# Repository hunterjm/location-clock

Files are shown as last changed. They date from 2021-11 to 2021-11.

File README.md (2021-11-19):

# Location Clock

Location Clock is inspired by a love of all things magical, and scientific. A combination of reading Harry Potter with my 8 year old and her "simple machines"
STEM lessons in school, we decided to embark on building our very own physical location clock. Already having Home Assistant setup and configured for my wife
and I, we chose to build upon that along with ESPHome.

## Build Guide

For a detailed build guide please visit the [GitHub Pages Website](https://hunterjm.github.io/location-clock).

## Inspiration

For this project, I drew inspiration from the following similar projects

1. [Magic Clock](https://github.com/brgerig/Magic-Clock): Most of the 3D print files for the assembly were used and/or remixed from here.
2. [Printable Props](https://printableprops.jimdo.com/en/harry-potter/weasley-clock/): Pascal Böcker graciously shared the STLs for the clock hands with me.

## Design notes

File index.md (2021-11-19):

A combination of reading Harry Potter with my 8 year old and her "simple machines"
STEM lessons in school, we decided to embark on building our very own physical location clock. Already having Home Assistant setup and configured for my wife
and I, we chose to build upon that along with ESPHome.

You can follow along here to build your own.

Clock Movement

## Inspiration

For this project, I drew inspiration from the following similar projects

1. [Magic Clock](https://github.com/brgerig/Magic-Clock): Most of the 3D print files for the assembly were used and/or remixed from here.
2. [Printable Props](https://printableprops.jimdo.com/en/harry-potter/weasley-clock/): Pascal Böcker graciously shared the STLs for the clock hands with me.

## Parts

| Part | Quantity | Price | My Source |
|---|---|---|---|
| [nodemcu-32s dev board (38 pin)][1] | 1 | $7-$12 | Amazon |
| [ULN2003 Board w/ Stepper Motor][2] | 4 | $10-$14 | Amazon |
| [Female to Female Jumper Wires][3] | ~26 | $5-7 | Amazon |
| [6V 2A AC/DC Adapter w/ Breakout][4] | 1 | $10-20 | Amazon |
| [Aluminum Telescopic Tubes][5] (1/8, 5/32, 3/16, 7/32) | 1 each size | $7-9 | Amazon |
| Transparent Paper Sheet | 1 | < $1 | On Hand |
| Transparent Vinyl Sticker Sheet | 1 | < $1 | On Hand |
| #10-24 x 3" Machine Screws | 4 | $2-$4 | Big Box Store |
| #10-24 T-Nuts | 4 | $1-$2 | Big Box Store |
| #10-24 Nuts | 24 | $2-$4 | Big Box Store |
| Small Wood Screws | 6 | $1-$2 | Big Box Store |
| 1/2" MDF/Wood Block/Plywood/Scrap Wood | 1 | ? | On Hand |
| White Spray Paint | 1 | ? | On Hand |
| Metallic Silver Spray Paint | 1 | ? | On Hand |
| Super Glue & Wood Glue | 1 | ? | On Hand |
| Old Clock Body (Mine was a Regulator 1114c) | 1 | $25-$35 | Facebook |
| **Total** | | **< $100**  | |

## 3D Printed Parts

| Part | Quantity |
|---|---|
| ULN2003 dual case ([base][6], [cover][7]) | 2 |
| [Mounting Bracket Base][8] | 1 |
| Mounting Bracket Top ([clean][9] or [threaded][10] & [plug][11]) | 1 |
| [Spur Gear 5mm][12] | 4 |
| [Spur Gear 1/8][13] | 1 |
| [Spur Gear 5/32][14] | 1 |
| [Spur Gear 3/16][15] | 1 |
| [Spur Gear 7/32][16] | 1 |
| Clock Hands (not mine to share) | 4 |

## Tools & Supplies

- Phillips Screwdriver
- Exacto Knife
- Super Glue
- Wood Glue
- Wood Clamps
- Spray Paint (White & Metallic Silver)
- Hand saw w/ metal cutting blade
- Wood saw
- Drill & bits
- Pick (helps remove staples)
- Soldering Iron
- (optional) Bench Grinder

## Software

The SVGs in the [graphics folder](https://github.com/hunterjm/location-clock/tree/main/graphics) were created in Inkscape and are editable to change your locations and names. The `names.svg` file has a hidden layer with a to-scale copy of the clock hands I printed for alignment.

## Flash Your ESP32

Insert ESP Web Tools here. Until then, the configuration [can be found here](https://github.com/hunterjm/location-clock/blob/main/esphome/location-clock.yaml).

## The Build

Assembly of the control mechanism was the most difficult part of this project, and I did not take near enough pictures or notes of the process. That being said, a lot of it
is pretty self explanitory, so I will give a general overview of the steps I took and some gotchas along the way.

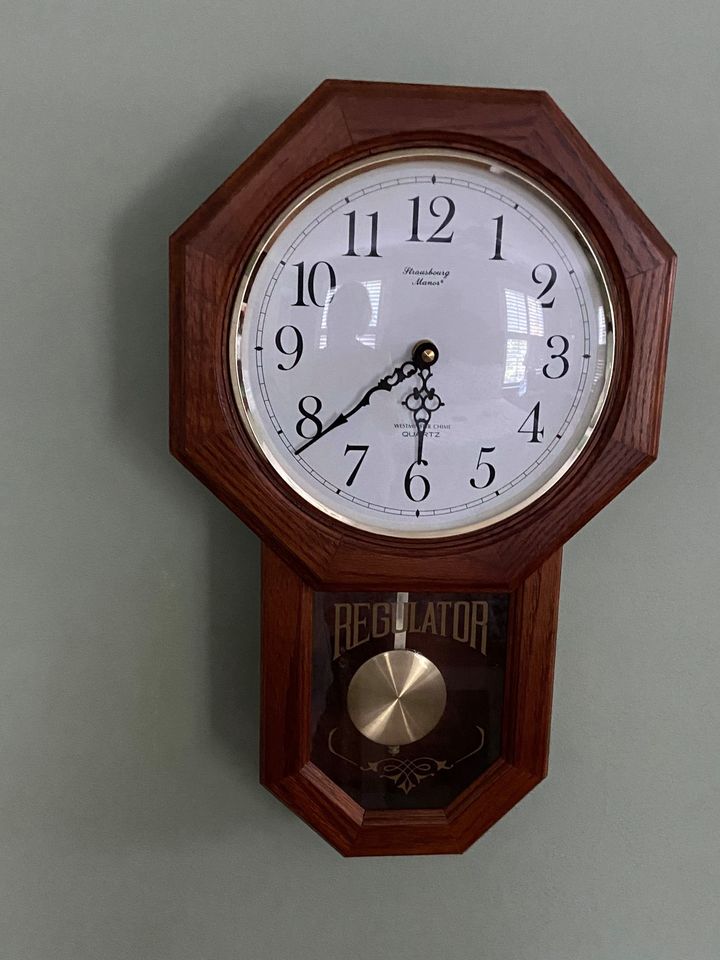
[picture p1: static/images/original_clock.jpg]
Original Clock


### Clock Tear Down

1. 4 screws held the glass assembly of the clock face on from the inside of the body.
2. The clock hands pull right off - they require some pressure.
3. Remove the nut from the clock face, and the old time mechanism should come right out.
4. The glass was held in with a plastic support held by two small screws. Remove the glass so it doesn't break. I also used a razor blade to scrape off the "REGULATOR" text from the glass.
5. The face was held on with 4 L brackets on the side of the clock. I removed it for easier access to build the mechanism.
5. The clock face was attached with some double sided tape and pulled right off.
6. There was a pre-existing 1/2 block of wood in the clock body that was too small and needed to be removed. It was held on with 2 staples, but no glue. I used a pick to pull the staples out.

### Clock Face

1. I spray painted over the aluminum clock face with flat white paint to cover the old numbers.
2. I created a [new face](https://github.com/hunterjm/location-clock/blob/main/graphics/clock_face.svg) in Inkscape and printed it on the vinyl sticker paper.
3. After the paint dried, I was able to apply the new face to the old aluminum one and trim it down with an exacto knife.
Clock Face

### Clock Hands

I am unable to provide the STL files for the hands at this time. I am working with the original author to see if he will let me share them with you all. Either way, the below steps were taken for the clock hands.

1. Spray paint them Metallic Silver.
2. Super Glue them to the transparent paper.
3. Cut out the hands with an exacto knife.
Clock Hands

### Motor Mechanism

Here is where I didn't take nearly enough pictures, and for that I'm sorry!

1. Cut your 1/2" MDF/Scrap Wood/Plywood down to size to fit inside the clock.
2. Using the top mounting bracket as a template, drill holes through the wood for the center piece and the 4 #10 screws in the corners.
3. Hammer in the T-Nuts to the back of the board.
4. Cut off the heads of the 3" #10 screws and thread a nut through to fix the threads. You can use a bench grinder to clean up the cuts, but it's not necessary.
5. Thread the cut off end through the board and into the T-Nuts.
6. Place the top mounting bracket onto the new threaded rods and add 4 nuts.
7. In a clockwise motion, place the motors (attached to the brackets and with the gears on) with the height of two nuts between them. The first two should be facing up, and the following two facing down for the most compact assembly. The gears on the two facing down will actually be lower than those on the motors facing up below them. See picture below for how I have mine setup.
8. Starting with the largest aluminum rod, thread it through the assembly and mark where it contacts the gear and give yourself plenty of space sticking out of the front to attach hands. Cut it with your hand saw, and clean it up with the exacto knife and/or bench grinder. **Make sure you do not bend the rod!** Verify the step smaller rod can still move freely inside.
9. Super glue the gear to one end of the aluminum rod and finess it into the mechanism so the gears are touching.
10. Rinse and repeat for the next 2 rods.  **Read the next line before cutting the last rod!** It's OK if things feel tight and like they aren't lining up properly. Clearances are tight. Until your rods have preassure on all 4 sides from all 4 motors, you will probably have to push and prod and pull and curse.
11. The last rod has a place to fit into the mounting bracket base, so it will be a little longer, and the gear won't be glued on to the end. Make sure you attach the bracket base and measure from the front of the clock!
Motors
12. Wood glue the completed mechanism to the back of the clock face and clamp to let dry.

### Assembly

1. Before re-attaching the clock face, find locations inside the clock body for all of your motor controllers and ESP32. I did not print a mount for my ESP, it's just hanging out back there.
2. Wire up everything inside (except the motors, which are on the clock face). The wiring diagrams are below. The only soldering you will need is to make the power harness. The ESP32 board and each of the ULN2003 boards need 5V power.
3. Re-insert the glass
4. Attach the clock face, watch out for wires, and triple check nothing got unseated during handling.
5. Plug in the motors. Which board you plug each motor into matters if you want to use the out of the box firmware for your ESP32! Check the diagram!
6. Wire management
7. Attach the hands to the face of the clock and align them all to the same location, probably "Home".
8. Power it on and try moving each motor in the Home Assistant Developer Tools "Services" section.
9. Troubleshoot and try again :)

## Wiring Diagrams

### Breadboard
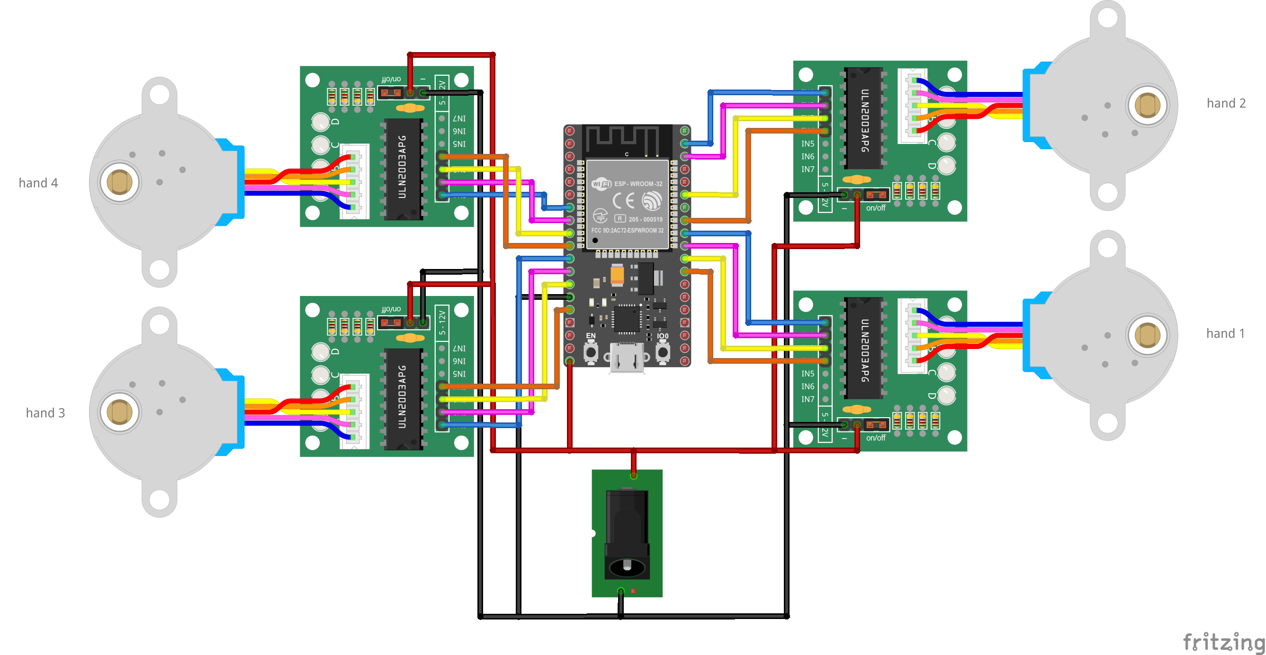
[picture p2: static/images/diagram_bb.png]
Breadboard Diagram


### Schematic
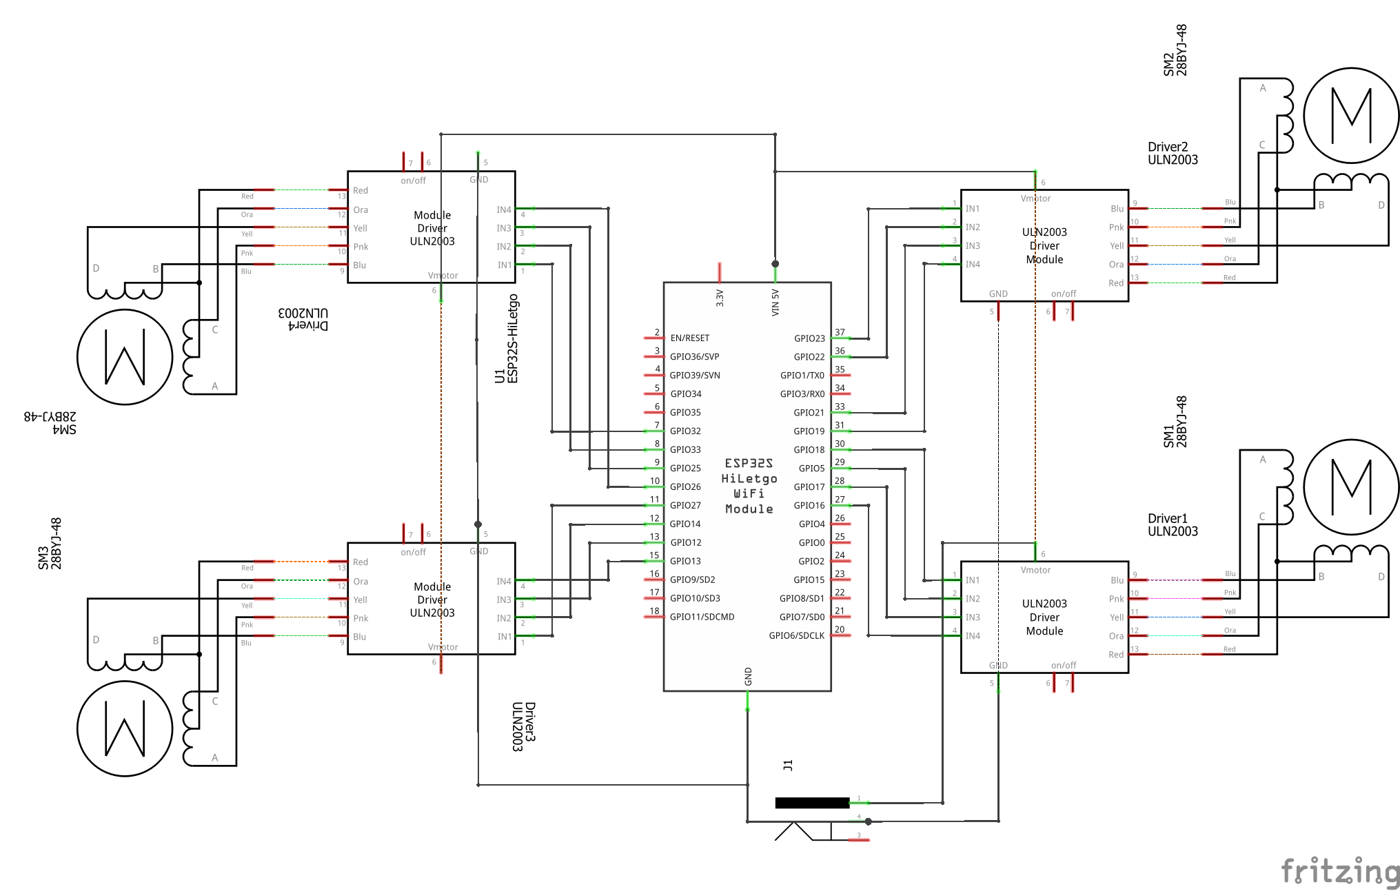
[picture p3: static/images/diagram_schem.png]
Schematic Diagram


## Home Assistant

### Zones

Home Assistant [Zones](https://www.home-assistant.io/integrations/zone/) are the star of the show here. Set up as many Zones as you can for the locations on your clock face.  Don't worry now if the Zone shares the same name as the location on the clock. Not everyone in the household will work at the same place or go to the same school for instance. Name them what they are, we will account for that in the template sensor we create later.

### Template Sensors

To map Zones to locations on the clock and implement some additional logic for locations like "Traveling", "Lost", and "Vacation" we will be using a [Template Sensor](https://www.home-assistant.io/integrations/template/) in Home Assistant. You can see what mine looks like below:

{% raw %}
```yaml
sensor:
  - platform: template
    sensors:
      jason_presence:
        value_template: >
          {% if is_state('person.jason', 'home') %}
            Home
          {% elif is_state('person.jason', 'not_home') or is_state('person.jason', 'Library') %}
            {% if distance('device_tracker.jasons_iphone') > 80 %}
              Vacation
            {% elif as_timestamp(now()) - as_timestamp(states.person.jason.last_changed) > 86400 %}
              Lost
            {% elif is_state('sensor.jasons_iphone_activity', 'Automotive') %}
              Traveling
            {% else %}
              Away
            {% endif %}
          {% elif is_state('person.jason', 'Nana') or is_state('person.jason', 'Gran') %}
            Parents
          {% elif is_state('person.jason', 'Son School') or is_state('person.jason', 'Daughter School') %}
            School
          {% elif is_state('person.jason', 'Dentist') %}
            Doctor
          {% elif is_state('person.jason', 'Charlotte FC') %}
            Event
          {% else %}
            {{ states('person.jason') }}
          {% endif %}
```
{% endraw %}

To better understand the logic here, I have a Zone for "Library". That is where my Wife works, but I do not. I want the "Away" logic to run when I am there. For my "Away" logic, there are 4 possible "Away" states:
1. Vacation: Away, but > 80 km from home.
2. Lost: Away for more than 24 hours excluding "Vacation".
3. Traveling: Away but iPhone reports activity as "Automotive", excluding "Vacation" and "Lost".
4. Away: Simply not home when none of the above special states are met.

### Children

The children aren't old enough for phones yet, and cheap GPS devices targeted for Kids are [notoriously insecure](https://www.troyhunt.com/how-to-track-your-kids-and-other-peoples-kids-with-the-tictoctrack-watch/). Because of this, I am simply using an [Input Select](https://www.home-assistant.io/integrations/input_select/) with all of the clock face locations for the kids hands currently. You can then create automations to automatically change them under certian conditions. For example, if my wife or I enter the Zone for a child's school in the morning, we can place them at "School". Same thing with picking them up in the afternoon. When they get old enough, this can all be automated through the Mobile App like it is for the adults.

### Blueprint

The [blueprint](https://github.com/hunterjm/location-clock/blob/main/homeassistant/blueprints/location-clock.yaml) is meant to create an automation to control each hand. There is a detailed description in the blueprint on how it should be configured. Click the link below to import it!



[1]: <https://www.amazon.com/dp/B0718T232Z>
[2]: <https://www.amazon.com/dp/B015RQ97W8>
[3]: <https://www.amazon.com/dp/B01L5ULRUA>
[4]: <https://www.amazon.com/dp/B08VWG1S1V>
[5]: <https://www.amazon.com/dp/B07VS4823F>
[6]: <https://github.com/hunterjm/location-clock/blob/main/stl_files/ULN2003-dual.stl>
[7]: <https://github.com/hunterjm/location-clock/blob/main/stl_files/ULN2003-dual-cover.stl>
[8]: <https://github.com/hunterjm/location-clock/blob/main/stl_files/mounting-bracket-base.stl>
[9]: <https://github.com/hunterjm/location-clock/blob/main/stl_files/mounting-bracket-top.stl>
[10]: <https://github.com/hunterjm/location-clock/blob/main/stl_files/mounting-bracket-top-threaded.stl>
[11]: <https://github.com/hunterjm/location-clock/blob/main/stl_files/mounting-bracket-top-threaded-plug.stl>
[12]: <https://github.com/hunterjm/location-clock/blob/main/stl_files/spur_gear_5mm.stl>
[13]: <https://github.com/hunterjm/location-clock/blob/main/stl_files/spur-gear-1-8th.stl>
[14]: <https://github.com/hunterjm/location-clock/blob/main/stl_files/spur-gear-5-32nd.stl>
[15]: <https://github.com/hunterjm/location-clock/blob/main/stl_files/spur-gear-3-16th.stl>
[16]: <https://github.com/hunterjm/location-clock/blob/main/stl_files/spur-gear-7-32.stl>

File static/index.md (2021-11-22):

From a combination of reading Harry Potter with my 8 year old and her "simple machines"
STEM lessons in school, we decided to embark on building our very own physical location clock. Already having Home Assistant set up and configured for my wife
and I, we chose to build upon that along with ESPHome.

You can follow along here to build your own.

- [Inspiration](#inspiration)
- [Setup](#setup)
- [Flash Your ESP32](#flash-your-esp32)
- [The Build](#the-build)
- [Wiring Diagrams](#wiring-diagrams)
- [Home Assistant](#home-assistant)

Clock Movement

## Inspiration

For this project, I drew inspiration from the following similar projects

1. [Magic Clock](https://github.com/brgerig/Magic-Clock): Most of the 3D print files for the assembly were used and/or remixed from here.
2. [Printable Props](https://printableprops.jimdo.com/en/harry-potter/weasley-clock/): Pascal Böcker graciously shared the STLs for the clock hands with me.

## Setup

### Parts

| Part | Quantity | Price | My Source |
|---|---|---|---|
| [nodemcu-32s dev board (38 pin)][1] | 1 | $7-$12 | Amazon |
| [ULN2003 Board w/ Stepper Motor][2] | 4 | $10-$14 | Amazon |
| [Female to Female Jumper Wires][3] | ~26 | $5-7 | Amazon |
| [6V 2A AC/DC Adapter w/ Breakout][4] | 1 | $10-20 | Amazon |
| [Aluminum Telescopic Tubes][5] (1/8, 5/32, 3/16, 7/32) | 1 each size | $7-9 | Amazon |
| Transparent Paper Sheet | 1 | < $1 | On Hand |
| Transparent Vinyl Sticker Sheet | 1 | < $1 | On Hand |
| #10-24 x 3" Machine Screws | 4 | $2-$4 | Big Box Store |
| #10-24 T-Nuts | 4 | $1-$2 | Big Box Store |
| #10-24 Nuts | 24 | $2-$4 | Big Box Store |
| Small Wood Screws | 6 | $1-$2 | Big Box Store |
| 1/2" MDF/Wood Block/Plywood/Scrap Wood | 1 | ? | On Hand |
| White Spray Paint | 1 | ? | On Hand |
| Metallic Silver Spray Paint | 1 | ? | On Hand |
| Super Glue & Wood Glue | 1 | ? | On Hand |
| Old Clock Body (Mine was a Regulator 1114c) | 1 | $25-$35 | Facebook |
| **Total** | | **< $100**  | |

### 3D Printed Parts

| Part | Quantity |
|---|---|
| ULN2003 dual case ([base][6], [cover][7]) | 2 |
| [Mounting Bracket Base][8] | 1 |
| Mounting Bracket Top ([clean][9] or [threaded][10] & [plug][11]) | 1 |
| [Spur Gear 5mm][12] | 4 |
| Spur Gear ([1/8][13], [5/32][14], [3/16][15], [7/32][16]) | 1 each |
| Clock Hand ([1][17], [2][18], [3][19], [4][20]) | 1 each |

### Tools & Supplies

- Phillips Screwdriver
- Exacto Knife
- Super Glue
- Wood Glue
- Wood Clamps
- Spray Paint (White & Metallic Silver)
- Hand saw w/ metal cutting blade
- Wood saw
- Drill & bits
- Pick (helps remove staples)
- Soldering Iron
- (optional) Bench Grinder

### Software

The SVGs in the [graphics folder](https://github.com/hunterjm/location-clock/tree/main/graphics) were created in Inkscape and are editable to change your locations and names. The `names.svg` file has a hidden layer with a to-scale copy of the clock hands I printed for alignment. They use the Lumos font face.

## Flash Your ESP32

The ESPHome configuration [can be found here](https://github.com/hunterjm/location-clock/blob/main/esphome/location-clock.yaml). With ESP Web Tools, you can flash and configure your ESP32 directly from a supported browser with the compiled firmware by plugging it in and clicking the button below.

<esp-web-install-button manifest="./firmware/manifest.json"></esp-web-install-button>

<script type="module" src="https://unpkg.com/esp-web-tools@5.2.0/dist/web/install-button.js?module"></script>

## The Build

Assembly of the control mechanism was the most difficult part of this project, and I did not take near enough pictures or notes of the process. That being said, a lot of it
is pretty self explanitory, so I will give a general overview of the steps I took and some gotchas along the way.

Original Clock

### Clock Tear Down

1. 4 screws held the glass assembly of the clock face on from the inside of the body.
2. The clock hands pull right off - they require some pressure.
3. Remove the nut from the clock face, and the old time mechanism should come right out.
4. The glass was held in with a plastic support held by two small screws. Remove the glass so it doesn't break. I also used a razor blade to scrape off the "REGULATOR" text from the glass.
5. The face was held on with 4 L brackets on the side of the clock. I removed it for easier access to build the mechanism.
5. The clock face was attached with some double sided tape and pulled right off.
6. There was a pre-existing 1/2 block of wood in the clock body that was too small and needed to be removed. It was held on with 2 staples, but no glue. I used a pick to pull the staples out.

### Clock Face

1. I spray painted over the aluminum clock face with flat white paint to cover the old numbers.
2. I created a [new face](https://github.com/hunterjm/location-clock/blob/main/graphics/clock_face.svg) in Inkscape and printed it on the vinyl sticker paper.
3. After the paint dried, I was able to apply the new face to the old aluminum one and trim it down with an exacto knife.
Clock Face

### Clock Hands

The [clock hands](#3d-printed-parts) are reproductions of Arthur, Molly, Ron, and Bill's hands from the film made by Pascal Böcker of [Printable Props](https://printableprops.jimdo.com/en/harry-potter/weasley-clock/). I scaled down his originals to fit in my clock face and resized the holes for the aluminum rods I am using.

1. Spray paint them Metallic Silver.
2. Super Glue them to the transparent paper.
3. Cut out the hands with an exacto knife.
Clock Hands

### Motor Mechanism

Here is where I didn't take nearly enough pictures, and for that I'm sorry!

1. Cut your 1/2" MDF/Scrap Wood/Plywood down to size to fit inside the clock.
2. Using the top mounting bracket as a template, drill holes through the wood for the center piece and the 4 #10 screws in the corners.
3. Hammer in the T-Nuts to the back of the board.
4. Cut off the heads of the 3" #10 screws and thread a nut through to fix the threads. You can use a bench grinder to clean up the cuts, but it's not necessary.
5. Thread the cut off end through the board and into the T-Nuts.
6. Place the top mounting bracket onto the new threaded rods and add 4 nuts.
7. In a clockwise motion, place the motors (attached to the brackets and with the gears on) with the height of two nuts between them. The first two should be facing up, and the following two facing down for the most compact assembly. The gears on the two facing down will actually be lower than those on the motors facing up below them. See picture below for how I have mine setup.
8. Starting with the largest aluminum rod, thread it through the assembly and mark where it contacts the gear and give yourself plenty of space sticking out of the front to attach hands. Cut it with your hand saw, and clean it up with the exacto knife and/or bench grinder. **Make sure you do not bend the rod!** Verify the step smaller rod can still move freely inside.
9. Super glue the gear to one end of the aluminum rod and finess it into the mechanism so the gears are touching.
10. Rinse and repeat for the next 2 rods.  **Read the next line before cutting the last rod!** It's OK if things feel tight and like they aren't lining up properly. Clearances are tight. Until your rods have preassure on all 4 sides from all 4 motors, you will probably have to push and prod and pull and curse.
11. The last rod has a place to fit into the mounting bracket base, so it will be a little longer, and the gear won't be glued on to the end. Make sure you attach the bracket base and measure from the front of the clock!
Motors
12. Wood glue the completed mechanism to the back of the clock face and clamp to let dry.

### Assembly

1. Before re-attaching the clock face, find locations inside the clock body for all of your motor controllers and ESP32. I did not print a mount for my ESP, it's just hanging out back there.
2. Wire up everything inside (except the motors, which are on the clock face). The wiring diagrams are below. The only soldering you will need is to make the power harness. The ESP32 board and each of the ULN2003 boards need 5V power.
3. Re-insert the glass
4. Attach the clock face, watch out for wires, and triple check nothing got unseated during handling.
5. Plug in the motors. Which board you plug each motor into matters if you want to use the out of the box firmware for your ESP32! Check the diagram!
6. Wire management
7. Attach the hands to the face of the clock and align them all to the same location, probably "Home".
8. Power it on and try moving each motor in the Home Assistant Developer Tools "Services" section.
9. Troubleshoot and try again :)

## Wiring Diagrams

### Breadboard
Breadboard Diagram

### Schematic
Schematic Diagram

## Home Assistant

### Zones

Home Assistant [Zones](https://www.home-assistant.io/integrations/zone/) are the star of the show here. Set up as many Zones as you can for the locations on your clock face.  Don't worry now if the Zone shares the same name as the location on the clock. Not everyone in the household will work at the same place or go to the same school for instance. Name them what they are, we will account for that in the template sensor we create later.

### Template Sensors

To map Zones to locations on the clock and implement some additional logic for locations like "Traveling", "Lost", and "Vacation" we will be using a [Template Sensor](https://www.home-assistant.io/integrations/template/) in Home Assistant. You can see what mine looks like below:

{% raw %}
```yaml
sensor:
  - platform: template
    sensors:
      jason_presence:
        value_template: >
          {% if is_state('person.jason', 'home') %}
            Home
          {% elif is_state('person.jason', 'not_home') or is_state('person.jason', 'Library') %}
            {% if distance('device_tracker.jasons_iphone') > 80 %}
              Vacation
            {% elif as_timestamp(now()) - as_timestamp(states.person.jason.last_changed) > 86400 %}
              Lost
            {% elif is_state('sensor.jasons_iphone_activity', 'Automotive') %}
              Traveling
            {% else %}
              Away
            {% endif %}
          {% elif is_state('person.jason', 'Nana') or is_state('person.jason', 'Gran') %}
            Parents
          {% elif is_state('person.jason', 'Son School') or is_state('person.jason', 'Daughter School') %}
            School
          {% elif is_state('person.jason', 'Dentist') %}
            Doctor
          {% elif is_state('person.jason', 'Charlotte FC') %}
            Event
          {% else %}
            {{ states('person.jason') }}
          {% endif %}
```
{% endraw %}

To better understand the logic here, I have a Zone for "Library". That is where my Wife works, but I do not. I want the "Away" logic to run when I am there. For my "Away" logic, there are 4 possible "Away" states:
1. Vacation: Away, but > 80 km from home.
2. Lost: Away for more than 24 hours excluding "Vacation".
3. Traveling: Away but iPhone reports activity as "Automotive", excluding "Vacation" and "Lost".
4. Away: Simply not home when none of the above special states are met.

### Children

The children aren't old enough for phones yet, and cheap GPS devices targeted for Kids are [notoriously insecure](https://www.troyhunt.com/how-to-track-your-kids-and-other-peoples-kids-with-the-tictoctrack-watch/). Because of this, I am simply using an [Input Select](https://www.home-assistant.io/integrations/input_select/) with all of the clock face locations for the kids hands currently. You can then create automations to automatically change them under certian conditions. For example, if my wife or I enter the Zone for a child's school in the morning, we can place them at "School". Same thing with picking them up in the afternoon. When they get old enough, this can all be automated through the Mobile App like it is for the adults.

### Blueprint

The [blueprint](https://github.com/hunterjm/location-clock/blob/main/homeassistant/blueprints/location-clock.yaml) is meant to create an automation to control each hand. There is a detailed description in the blueprint on how it should be configured. Click the link below to import it!



[1]: <https://www.amazon.com/dp/B0718T232Z>
[2]: <https://www.amazon.com/dp/B015RQ97W8>
[3]: <https://www.amazon.com/dp/B01L5ULRUA>
[4]: <https://www.amazon.com/dp/B08VWG1S1V>
[5]: <https://www.amazon.com/dp/B07VS4823F>
[6]: <https://github.com/hunterjm/location-clock/blob/main/stl_files/ULN2003-dual.stl>
[7]: <https://github.com/hunterjm/location-clock/blob/main/stl_files/ULN2003-dual-cover.stl>
[8]: <https://github.com/hunterjm/location-clock/blob/main/stl_files/mounting-bracket-base.stl>
[9]: <https://github.com/hunterjm/location-clock/blob/main/stl_files/mounting-bracket-top.stl>
[10]: <https://github.com/hunterjm/location-clock/blob/main/stl_files/mounting-bracket-top-threaded.stl>
[11]: <https://github.com/hunterjm/location-clock/blob/main/stl_files/mounting-bracket-top-threaded-plug.stl>
[12]: <https://github.com/hunterjm/location-clock/blob/main/stl_files/spur_gear_5mm.stl>
[13]: <https://github.com/hunterjm/location-clock/blob/main/stl_files/spur-gear-1-8th.stl>
[14]: <https://github.com/hunterjm/location-clock/blob/main/stl_files/spur-gear-5-32nd.stl>
[15]: <https://github.com/hunterjm/location-clock/blob/main/stl_files/spur-gear-3-16th.stl>
[16]: <https://github.com/hunterjm/location-clock/blob/main/stl_files/spur-gear-7-32.stl>
[17]: <https://github.com/hunterjm/location-clock/blob/main/stl_files/hand-1-1-8th.stl>
[18]: <https://github.com/hunterjm/location-clock/blob/main/stl_files/hand-2-5-32nd.stl>
[19]: <https://github.com/hunterjm/location-clock/blob/main/stl_files/hand-3-3-16th.stl>
[20]: <https://github.com/hunterjm/location-clock/blob/main/stl_files/hand-4-7-32nd.stl>

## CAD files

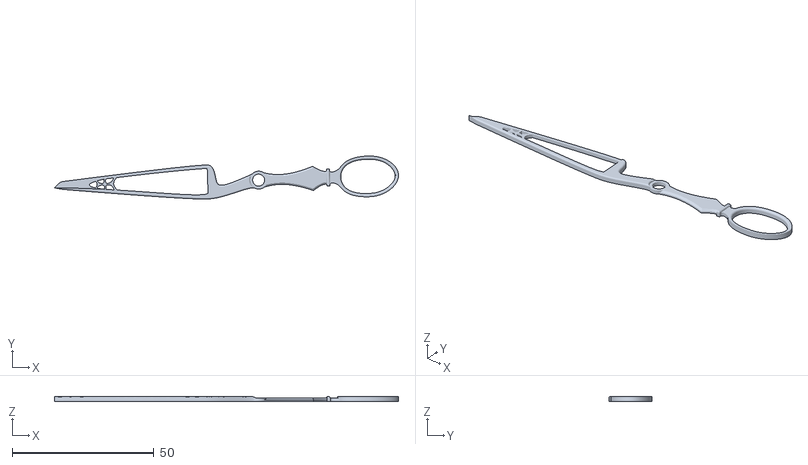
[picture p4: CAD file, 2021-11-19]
stl_files/hand-2-5-32nd.stl
121.4 x 15.2 x 1.80

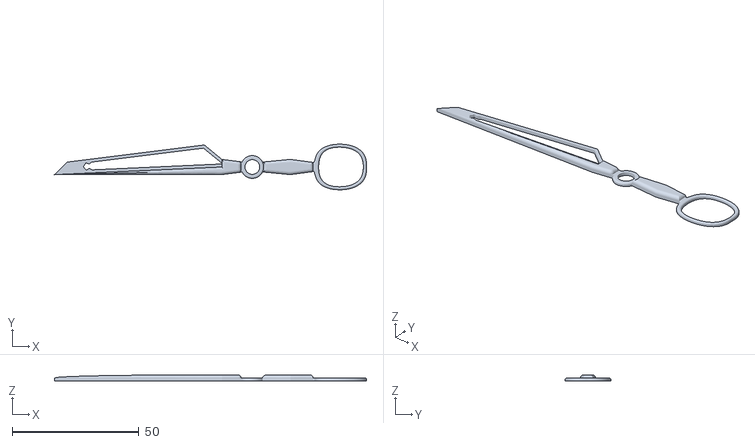
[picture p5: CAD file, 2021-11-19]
stl_files/hand-4-7-32nd.stl
123.0 x 18.0 x 2.40

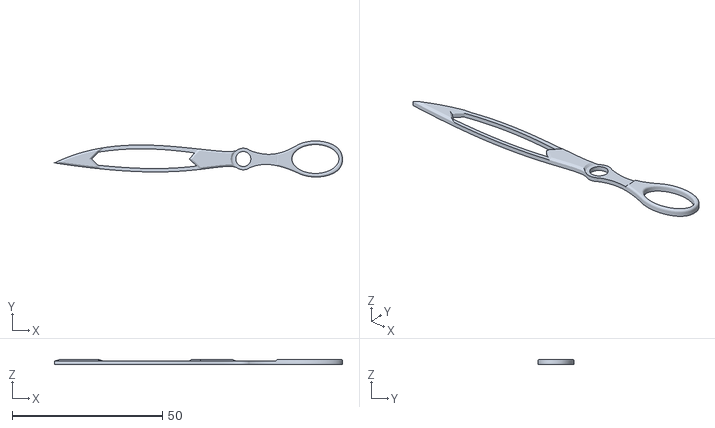
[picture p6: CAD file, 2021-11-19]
stl_files/hand-3-3-16th.stl
95.8 x 12.0 x 1.80

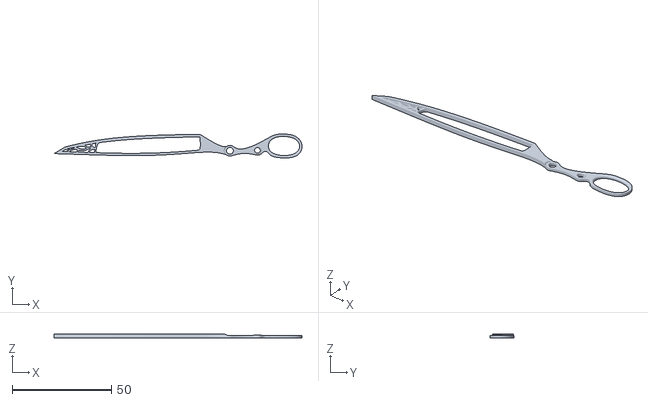
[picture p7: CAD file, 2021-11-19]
stl_files/hand-1-1-8th.stl
124.8 x 12.0 x 1.80

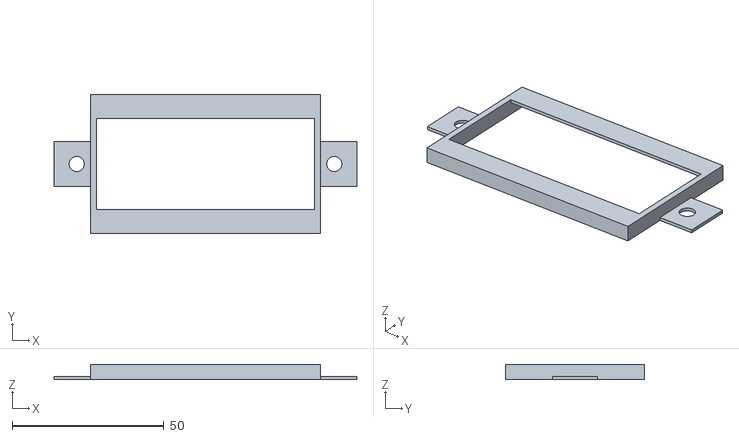
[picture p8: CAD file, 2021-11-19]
stl_files/ULN2003-dual-cover.stl
100.0 x 46.0 x 5.00

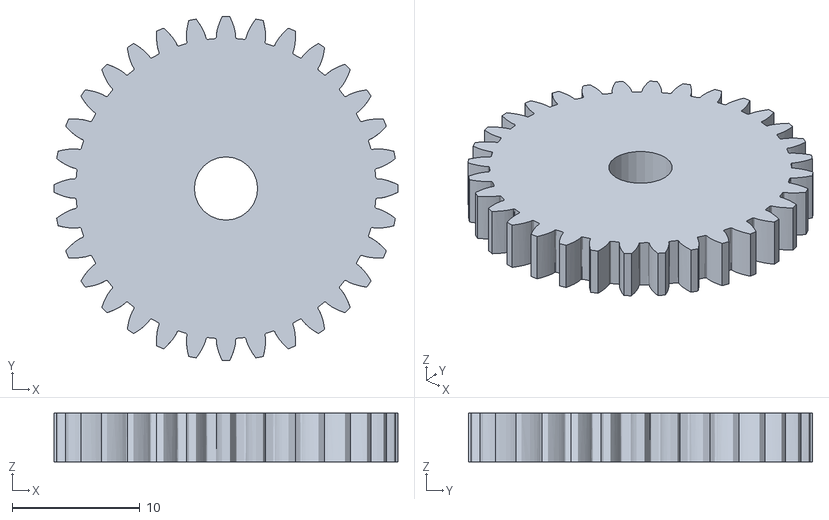
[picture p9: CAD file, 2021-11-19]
stl_files/spur-gear-3-16th.stl
27.0 x 27.0 x 3.81

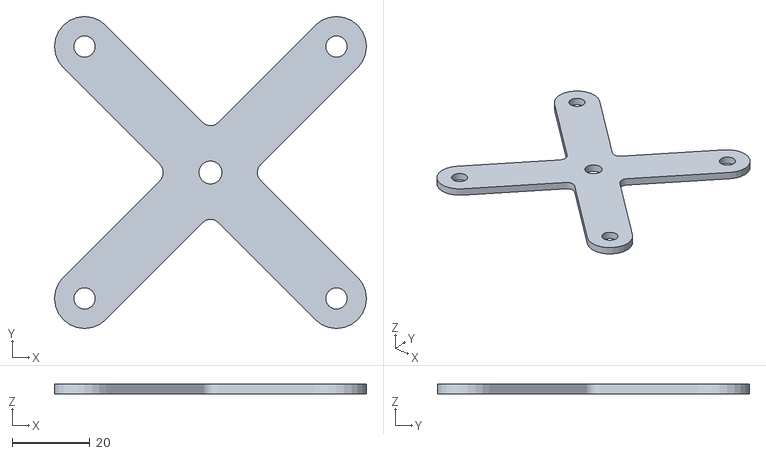
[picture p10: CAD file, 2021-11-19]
stl_files/mounting-bracket-top.stl
80.5 x 80.5 x 2.50

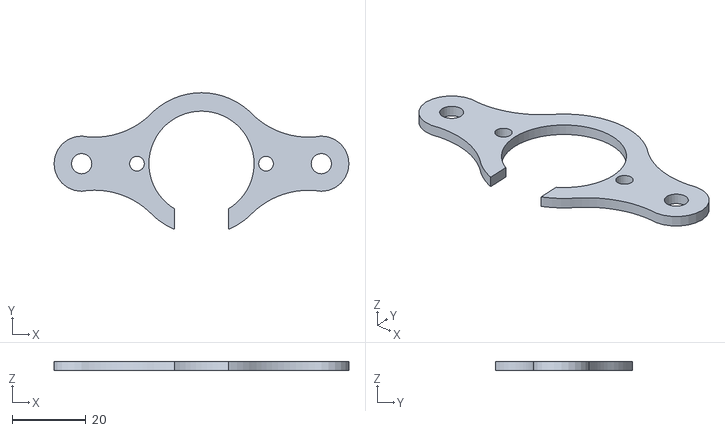
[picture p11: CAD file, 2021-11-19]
stl_files/mounting-bracket.stl
80.0 x 37.0 x 2.50

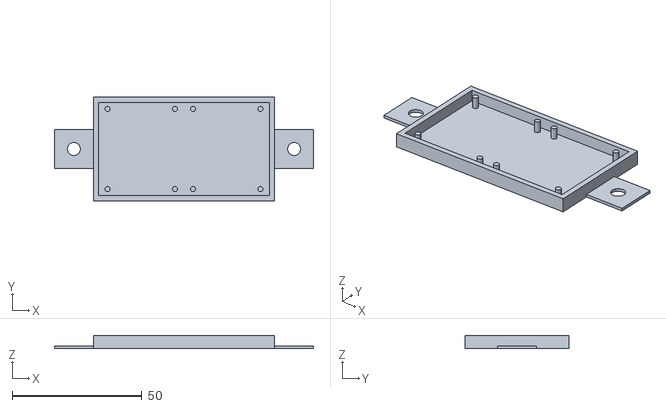
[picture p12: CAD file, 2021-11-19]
stl_files/ULN2003-dual.stl
100.0 x 40.0 x 5.00

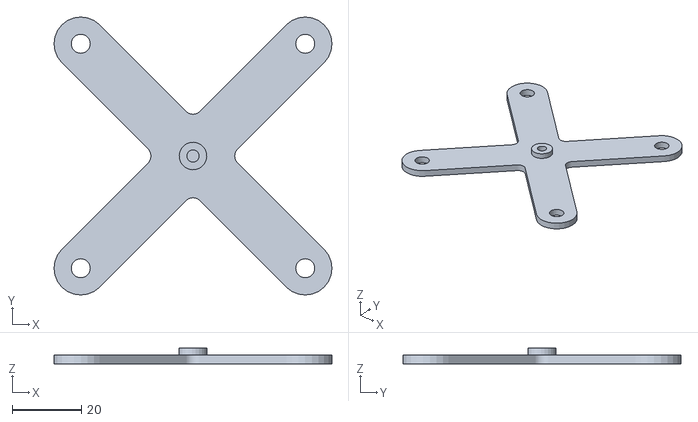
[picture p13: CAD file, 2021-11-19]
stl_files/mounting-bracket-base.stl
80.5 x 80.5 x 4.50

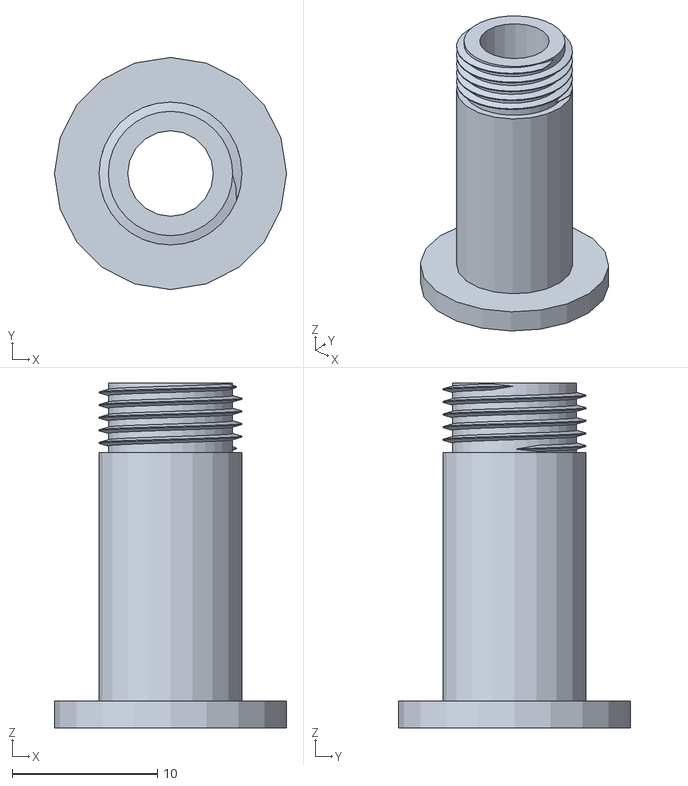
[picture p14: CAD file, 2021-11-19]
stl_files/mounting-bracket-top-threaded-plug.stl
16.0 x 16.0 x 23.8

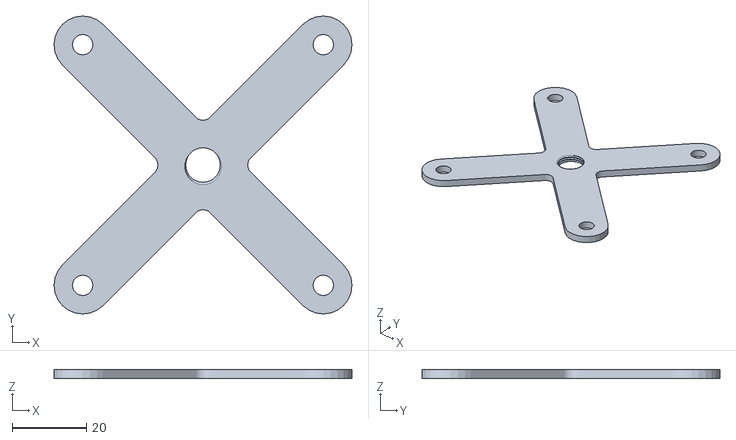
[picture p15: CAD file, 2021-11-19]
stl_files/mounting-bracket-top-threaded.stl
80.5 x 80.5 x 2.50

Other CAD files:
stl_files/spur_gear_5mm.stl
stl_files/spur-gear-5-32nd.stl
stl_files/spur-gear-7-32.stl
stl_files/spur-gear-1-8th.stl

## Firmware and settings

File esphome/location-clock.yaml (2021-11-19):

substitutions:
  name: location-clock

esphome:
  name: "${name}"
  platform: ESP32
  board: nodemcu-32s
  name_add_mac_suffix: true
  project:
    name: hunterjm.location_clock
    version: "1.0.0"

dashboard_import:
  package_import_url: github://hunterjm/location-clock/esphome/location-clock.yaml@v1

# Enable logging
logger:

# Allow OTA updates
ota:

# Allow provisioning Wi-Fi via serial
improv_serial:

# Sets up Bluetooth LE (Only on ESP32) to allow the user
# to provision wifi credentials to the device.
esp32_improv:
  authorizer: none

# Configure WiFi
wifi:
  # Set up a wifi access point
  ap:
    ssid: "Location Clock"

# In combination with the `ap` this allows the user
# to provision wifi credentials to the device via WiFi AP.
captive_portal:

# Enable Web Server
web_server:

# Enable Home Assistant API
api:
  services:
    - service: home_hands
      then:
        - stepper.report_position:
            id: hand_1
            position: 0
        - stepper.set_target:
            id: hand_1
            target: 0
        - stepper.report_position:
            id: hand_2
            position: 0
        - stepper.set_target:
            id: hand_2
            target: 0
        - stepper.report_position:
            id: hand_3
            position: 0
        - stepper.set_target:
            id: hand_3
            target: 0
        - stepper.report_position:
            id: hand_4
            position: 0
        - stepper.set_target:
            id: hand_4
            target: 0
    - service: control_hand_1
      variables:
        target: int
      then:
        - stepper.set_target:
            id: hand_1
            target: !lambda 'return target;'
    - service: control_hand_2
      variables:
        target: int
      then:
        - stepper.set_target:
            id: hand_2
            target: !lambda 'return target;'
    - service: control_hand_3
      variables:
        target: int
      then:
        - stepper.set_target:
            id: hand_3
            target: !lambda 'return target;'
    - service: control_hand_4
      variables:
        target: int
      then:
        - stepper.set_target:
            id: hand_4
            target: !lambda 'return target;'

# Stepper Motors
stepper:
  - platform: uln2003
    id: hand_1
    pin_a: GPIO18
    pin_b: GPIO5
    pin_c: GPIO17
    pin_d: GPIO16
    sleep_when_done: true
    max_speed: 250 steps/s
  - platform: uln2003
    id: hand_2
    pin_a: GPIO23
    pin_b: GPIO22
    pin_c: GPIO21
    pin_d: GPIO19
    sleep_when_done: true
    max_speed: 250 steps/s
  - platform: uln2003
    id: hand_3
    pin_a: GPIO27
    pin_b: GPIO14
    pin_c: GPIO12
    pin_d: GPIO13
    sleep_when_done: true
    max_speed: 250 steps/s
  - platform: uln2003
    id: hand_4
    pin_a: GPIO32
    pin_b: GPIO33
    pin_c: GPIO25
    pin_d: GPIO26
    sleep_when_done: true
    max_speed: 250 steps/s

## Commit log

2021-11-19 add documentation on motor mechanism.
2021-11-19 Add mac to ESPHome device
2021-11-19 add STL for clock hands
    [hand-1-1-8th.stl, hand-2-5-32nd.stl, hand-3-3-16th.stl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]
